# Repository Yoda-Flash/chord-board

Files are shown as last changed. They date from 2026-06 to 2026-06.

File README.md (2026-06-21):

# Chord Board
The Chord Board is a MIDI controller, specifically designed for one to experiment with chords! 
Each note you play can be customized and looped.

I came up with this idea because I've always loved playing with different chords. 
I thought it would be cool to be able to experiment with them without having an actual instrument with me, 
or needing to learn the chords and fingerings to hear different combinations.

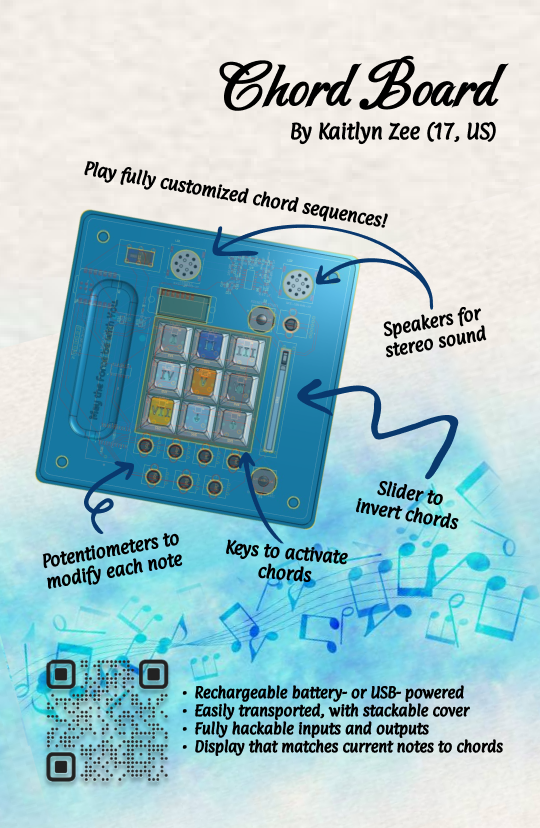
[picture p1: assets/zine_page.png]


## Images
### CAD
Top view:

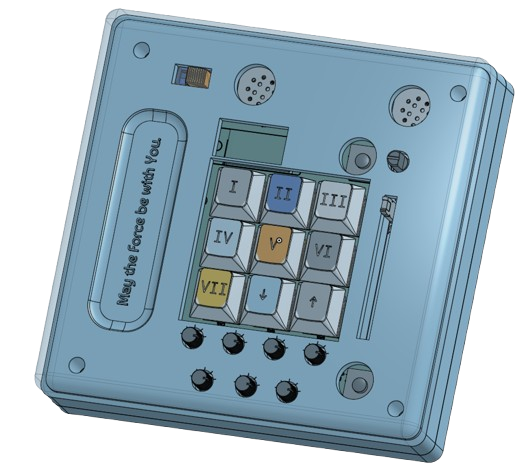
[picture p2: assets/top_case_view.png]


Bottom view:

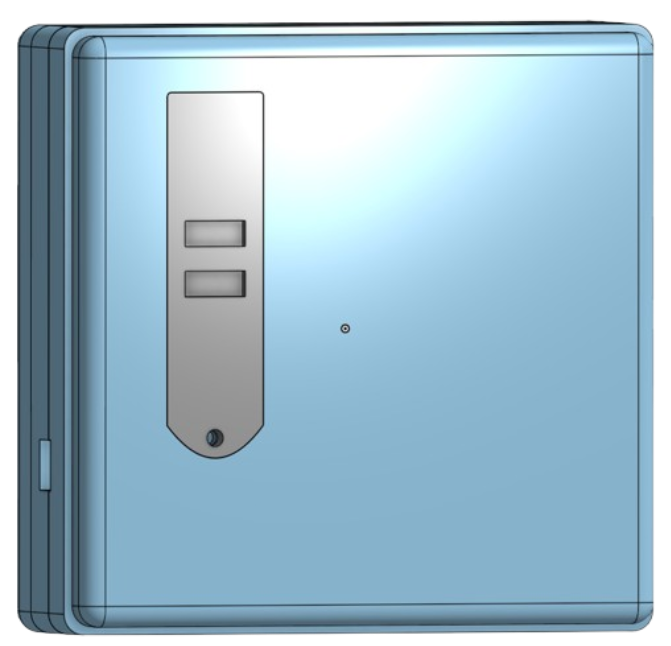
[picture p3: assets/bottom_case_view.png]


CAD of PCB with parts:

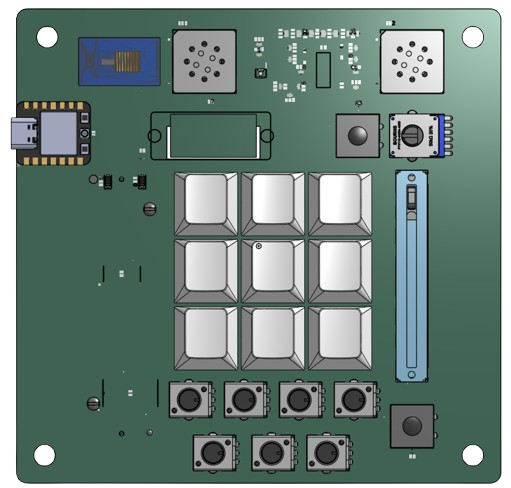
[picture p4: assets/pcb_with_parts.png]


### PCB
PCB:

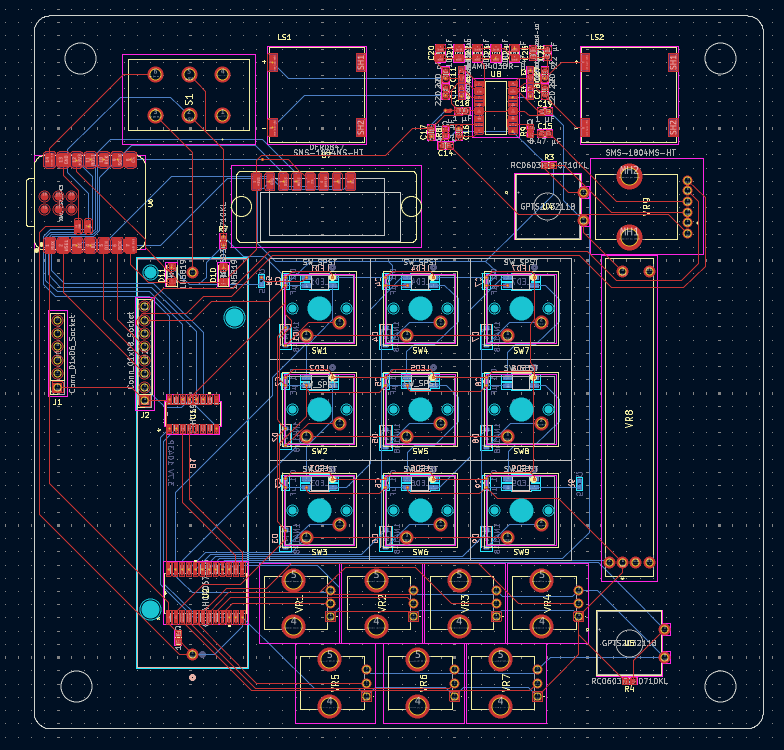
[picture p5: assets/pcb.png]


3D PCB Front:

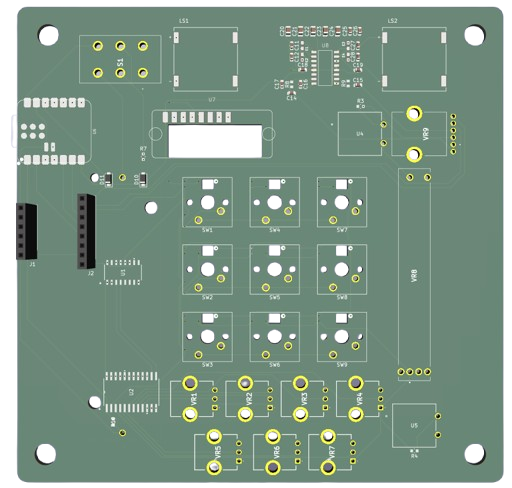
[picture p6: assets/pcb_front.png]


3D PCB Back:

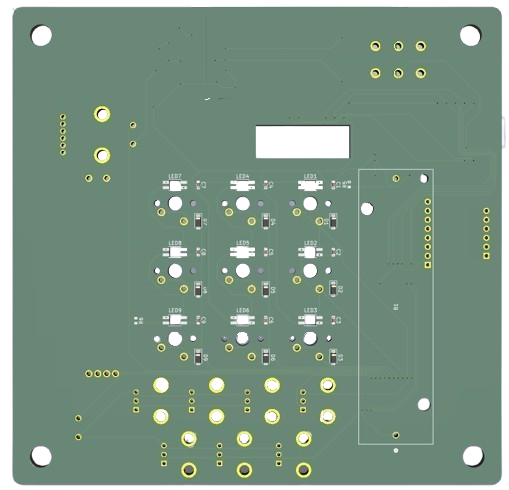
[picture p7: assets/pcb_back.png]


## Features
### Keypad
- 9 keys in a matrix
- 7 keys to activate chords
  - E.g. Pressing "I" will play the root chord, and "V" will play the fifth
- 2 keys to raise or lower the current key (default is C4)

### Rotary Potentiometers
- 7 knobs to modify chords
  - One knob for each note in the chord (1, 3, 5, 7, 9, 11, 13)
  - Each knob has 5 markings: ♭♭, ♭, no modification, #, ## (from left to right)
  - Modifications get applied to the next chord activated
  - If you don't want to include the note in the chord, just rotate the knob to any other position
  - E.g. If the 1st knob is not modified, the 2nd knob is at ♭, and the 3rd knob is not modified, a minor triad will play
- 1 logarithmic knob to adjust volume

### Slide potentiometer
- Inverts the chord depending on how much you slide
  - E.g. If a minor triad is playing and you slide 1/3 of the way, the base note will become the 5th

### Latching buttons
- 1 to cycle through different octaves, between octaves 2 to 6
- 1 to record a loop
  - When pressed, the chord sequence and timing will be recorded
  - When released, the chord sequence will be played back until you re-record or press another key

### TFT Display
- Displays the current key, including the octave, and the notes of the chord being played
  - If the notes being played are matched with a chord, that chord's name will be displayed as well

### Speakers
- Stereo sound
- Left and right speakers connected to a Class D Amplifier

### Power system
- 18650 3.7 V battery 
  - When a USB is plugged into the microcontroller, it will automatically charge
- Switch to power the board on/off
- A cover secures the battery, to be screwed open
  - Comes with a groove for fingers to easily remove the cover

### Stackable Case Cover
- The case comes with a cover, so the device can be transported without fear of accidentally pressing keys or rotating knobs
- The cover can be stacked on the bottom cover, so it doesn't have to lie around when the device is in use

## Bill of Materials
[CSV](bom.csv)

[Excel XLSX](bom.xlsx)

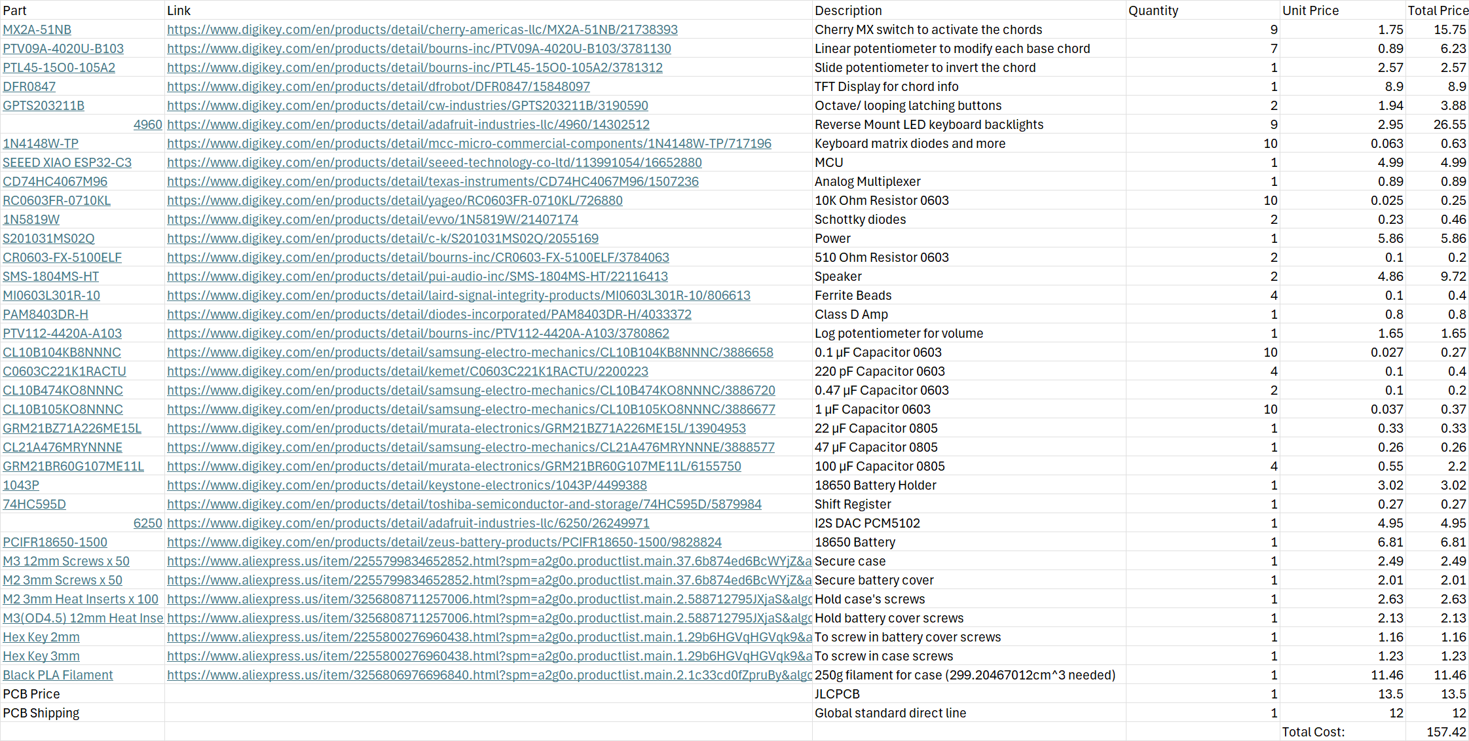
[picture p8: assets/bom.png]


## How to Set Up

### Build Instructions
Gather the assembled PCB and the 3D printed pieces in the [cad folder](./cad), as well as 4 sets of M3 12mm screws and heat inserts and 1 set of M2 3mm screws and heat inserts. 

Use a soldering iron to set the heat inserts in their respective holes (M2 3mm into the bottom case's back holes for the battery cover and M3 12mm for the bottom case's top holes for PCB mounting). Then, place the PCB in between the top and bottom case, and a battery and its cover into the slot on the back. Use a 2mm hex key to screw in the M2 screws and a 3mm hex key for the M3 one.

### Firmware Instructions
The firmware uses Circuit Python, 
so get started with it following https://learn.adafruit.com/welcome-to-circuitpython/installing-circuitpython

Within the Circuit Python drive, 
use pip to install the requirements in `requirements.txt` and transfer the files from `./firmware` to use!

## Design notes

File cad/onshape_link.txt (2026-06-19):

https://cad.onshape.com/documents/d37356e62e43a0eb5440c952/w/cc24309538963043d8ab08ae/e/3163c94926c0e795061b05d7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

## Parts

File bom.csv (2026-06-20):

Part | Link | Description | Quantity | Unit Price | Total Price
MX2A-51NB | https://www.digikey.com/en/products/detail/cherry-americas-llc/MX2A-51NB/21738393 | Cherry MX switch to activate the chords | 9 | 1.75 | 15.75
PTV09A-4020U-B103 | https://www.digikey.com/en/products/detail/bourns-inc/PTV09A-4020U-B103/3781130 | Linear potentiometer to modify each base chord | 7 | 0.89 | 6.23
PTL45-15O0-105A2 | https://www.digikey.com/en/products/detail/bourns-inc/PTL45-15O0-105A2/3781312 | Slide potentiometer to invert the chord | 1 | 2.57 | 2.57
DFR0847 | https://www.digikey.com/en/products/detail/dfrobot/DFR0847/15848097 | TFT Display for chord info | 1 | 8.9 | 8.9
GPTS203211B | https://www.digikey.com/en/products/detail/cw-industries/GPTS203211B/3190590 | Octave/ looping latching buttons | 2 | 1.94 | 3.88
4960 | https://www.digikey.com/en/products/detail/adafruit-industries-llc/4960/14302512 | Reverse Mount LED keyboard backlights | 9 | 2.95 | 26.55
1N4148W-TP | https://www.digikey.com/en/products/detail/mcc-micro-commercial-components/1N4148W-TP/717196 | Keyboard matrix diodes and more | 10 | 0.063 | 0.63
SEEED XIAO ESP32-C3 | https://www.digikey.com/en/products/detail/seeed-technology-co-ltd/113991054/16652880 | MCU | 1 | 4.99 | 4.99
CD74HC4067M96 | https://www.digikey.com/en/products/detail/texas-instruments/CD74HC4067M96/1507236 | Analog Multiplexer | 1 | 0.89 | 0.89
RC0603FR-0710KL | https://www.digikey.com/en/products/detail/yageo/RC0603FR-0710KL/726880 | 10K Ohm Resistor 0603 | 10 | 0.025 | 0.25
1N5819W | https://www.digikey.com/en/products/detail/evvo/1N5819W/21407174 | Schottky diodes | 2 | 0.23 | 0.46
S201031MS02Q | https://www.digikey.com/en/products/detail/c-k/S201031MS02Q/2055169 | Power | 1 | 5.86 | 5.86
CR0603-FX-5100ELF | https://www.digikey.com/en/products/detail/bourns-inc/CR0603-FX-5100ELF/3784063 | 510 Ohm Resistor 0603 | 2 | 0.1 | 0.2
SMS-1804MS-HT | https://www.digikey.com/en/products/detail/pui-audio-inc/SMS-1804MS-HT/22116413 | Speaker | 2 | 4.86 | 9.72
MI0603L301R-10 | https://www.digikey.com/en/products/detail/laird-signal-integrity-products/MI0603L301R-10/806613 | Ferrite Beads | 4 | 0.1 | 0.4
PAM8403DR-H | https://www.digikey.com/en/products/detail/diodes-incorporated/PAM8403DR-H/4033372 | Class D Amp | 1 | 0.8 | 0.8
PTV112-4420A-A103 | https://www.digikey.com/en/products/detail/bourns-inc/PTV112-4420A-A103/3780862 | Log potentiometer for volume | 1 | 1.65 | 1.65
CL10B104KB8NNNC | https://www.digikey.com/en/products/detail/samsung-electro-mechanics/CL10B104KB8NNNC/3886658 | 0.1 µF Capacitor 0603 | 10 | 0.027 | 0.27
C0603C221K1RACTU | https://www.digikey.com/en/products/detail/kemet/C0603C221K1RACTU/2200223 | 220 pF Capacitor 0603 | 4 | 0.1 | 0.4
CL10B474KO8NNNC | https://www.digikey.com/en/products/detail/samsung-electro-mechanics/CL10B474KO8NNNC/3886720 | 0.47 µF Capacitor 0603 | 2 | 0.1 | 0.2
CL10B105KO8NNNC | https://www.digikey.com/en/products/detail/samsung-electro-mechanics/CL10B105KO8NNNC/3886677 | 1 µF Capacitor 0603 | 10 | 0.037 | 0.37
GRM21BZ71A226ME15L | https://www.digikey.com/en/products/detail/murata-electronics/GRM21BZ71A226ME15L/13904953 | 22 µF Capacitor 0805 | 1 | 0.33 | 0.33
CL21A476MRYNNNE | https://www.digikey.com/en/products/detail/samsung-electro-mechanics/CL21A476MRYNNNE/3888577 | 47 µF Capacitor 0805 | 1 | 0.26 | 0.26
GRM21BR60G107ME11L | https://www.digikey.com/en/products/detail/murata-electronics/GRM21BR60G107ME11L/6155750 | 100 µF Capacitor 0805 | 4 | 0.55 | 2.2
1043P | https://www.digikey.com/en/products/detail/keystone-electronics/1043P/4499388 | 18650 Battery Holder | 1 | 3.02 | 3.02
74HC595D | https://www.digikey.com/en/products/detail/toshiba-semiconductor-and-storage/74HC595D/5879984 | Shift Register | 1 | 0.27 | 0.27
6250 | https://www.digikey.com/en/products/detail/adafruit-industries-llc/6250/26249971 | I2S DAC PCM5102 | 1 | 4.95 | 4.95
PCIFR18650-1500 | https://www.digikey.com/en/products/detail/zeus-battery-products/PCIFR18650-1500/9828824 | 18650 Battery | 1 | 6.81 | 6.81
M3 12mm Screws x 50 | https://www.aliexpress.us/item/2255799834652852.html?curPageLogUid=YDdz2iuLNXm6 | Secure case | 1 | 2.49 | 2.49
M2 3mm Screws x 50 | https://www.aliexpress.us/item/2255799834652852.html?curPageLogUid=YDdz2iuLNXm6 | Secure battery cover | 1 | 2.01 | 2.01
M2 3mm Heat Inserts x 100 | https://www.aliexpress.us/item/3256808711257006.html?curPageLogUid=6LOCmPzaGrDu | Hold case's screws | 1 | 2.63 | 2.63
M3(OD4.5) 12mm Heat Inserts x 100 | https://www.aliexpress.us/item/3256808711257006.html?curPageLogUid=6LOCmPzaGrDu | Hold battery cover screws | 1 | 2.13 | 2.13
Hex Key 2mm | https://www.aliexpress.us/item/2255800276960438.html?curPageLogUid=hPayhJG0pxXX | To screw in battery cover screws | 1 | 1.16 | 1.16
Hex Key 3mm | https://www.aliexpress.us/item/2255800276960438.html?curPageLogUid=hPayhJG0pxXX | To screw in case screws | 1 | 1.23 | 1.23
Black PLA Filament | https://www.aliexpress.us/item/3256806976696840.html?curPageLogUid=lXV8t9sE9sV8 | 250g filament for case (299.20467012cm^3 needed) | 1 | 11.46 | 11.46
PCB Price |  | JLCPCB | 1 | 13.5 | 13.5
PCB Shipping |  | Global standard direct line | 1 | 12 | 12
 |  |  |  | Total Cost: | 157.42

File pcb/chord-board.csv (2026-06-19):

Reference | Value | Datasheet | Footprint | Qty | DNP
B1 | 3.7V 1043P | 1043P | chord-board:BATT_1043P_KEY | 1
C1,C2,C3,C4,C5,C6,C7,C8,C9,C16 | 0.1 µF |  | Capacitor_SMD:C_0603_1608Metric | 10
C11,C12,C27,C28 | 220 pF |  | Capacitor_SMD:C_0603_1608Metric | 4
C14,C15 | 0.47 µF |  | Capacitor_SMD:C_0603_1608Metric | 2
C17,C18,C19,C25 | 1 µF |  | Capacitor_SMD:C_0603_1608Metric | 4
C20,C21,C22,C23 | 100 µF |  | Capacitor_SMD:C_0805_2012Metric | 4
C24 | 47 µF |  | Capacitor_SMD:C_0805_2012Metric | 1
C26 | 22 µF |  | Capacitor_SMD:C_0603_1608Metric | 1
D1,D2,D3,D4,D5,D6,D7,D8,D9 | 1N4148 | https://assets.nexperia.com/documents/data-sheet/1N4148_1N4448.pdf | Diode_SMD:D_SOD-123 | 9
D10,D11 | 1N5819 | http://www.vishay.com/docs/88525/1n5817.pdf | Diode_SMD:D_SOD-123F | 2
E1,E2,E3,E4 | MI0603L301R-10 |  | chord-board:FB_MI0603L301R-10 | 4
J1 | Conn_01x06_Socket |  | Connector_PinSocket_2.54mm:PinSocket_1x06_P2.54mm_Vertical | 1
J2 | Conn_01x08_Socket |  | Connector_PinSocket_2.54mm:PinSocket_1x08_P2.54mm_Vertical | 1
LED1,LED2,LED3,LED4,LED5,LED6,LED7,LED8,LED9 | SK6812-E 4960 | 4960 | chord-board:SK6812-E 4960_ADA | 9
LS1,LS2 | SMS-1804MS-HT |  | chord-board:SPKR_SMS-1804MS-HT | 2
R3,R4,R7 | RC0603FR-0710KL | RC0603FR-0710KL | chord-board:RC0603N_YAG | 3
R5,R6 | 510 Ω |  | chord-board:BO_CR0603 510 Ohms | 2
R8,R9,R10 | 10 kΩ |  | chord-board:BO_CR0603 510 Ohms,chord-board:RC0603N_YAG | 3
S1 | S201031MS02Q | https://www.digikey.ph/en/products/detail/c-k/S201031MS02Q/2055169?msockid=2ab7f999c9c96f4c2a13ec8dc8dd6eef | chord-board:S201031MS02Q | 1
SW1,SW2,SW3,SW4,SW5,SW6,SW7,SW8,SW9 | SW_SPST |  | Button_Switch_Keyboard:SW_Cherry_MX_1.00u_PCB | 9
U1 | 74HC595D | https://toshiba.semicon-storage.com/info/docget.jsp?did=36768&prodName=74HC595D | chord-board:SOIC16_TOS | 1
U2 | CD74HC4067M96 | https://www.ti.com/lit/gpn/cd74hc4067 | chord-board:CD74HC4067M96 DW24 | 1
U4,U5 | GPTS203211B | GPTS203211B | chord-board:SWITCH_03211B | 2
U6 | XIAO-ESP32-C3 |  | chord-board:XIAO-ESP32-C3-SMD | 1
U7 | DFR0847 |  | chord-board:DFR0874 SMD | 1
U8 | PAM8403DR-H |  | chord-board:PAM8403DR-H | 1
VR1,VR2,VR3,VR4,VR5,VR6,VR7 | PTV09A-4020U-B103 | https://www.bourns.com/docs/product-datasheets/PTV09.pdf | chord-board:PTV09A4020UB103 | 7
VR8 | PTL45-15O0-105A2 | https://www.bourns.com/docs/Product-Datasheets/PTL.pdf | chord-board:PTL4515O0105A2 | 1
VR9 | PTV112-4420A-A103 | https://componentsearchengine.com/Datasheets/1/PTV112-4420A-A103.pdf | chord-board:PTV1124420AA103 | 1

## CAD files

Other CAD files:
production/Chord Board Assembly.step
cad/PCB & Parts.step
cad/Bottom Case.step
cad/Key Caps.step
cad/Top Case.step
cad/Case Cover.step

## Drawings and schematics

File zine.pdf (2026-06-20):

# Chord Board

## By Kaitlyn Zee (17, US)

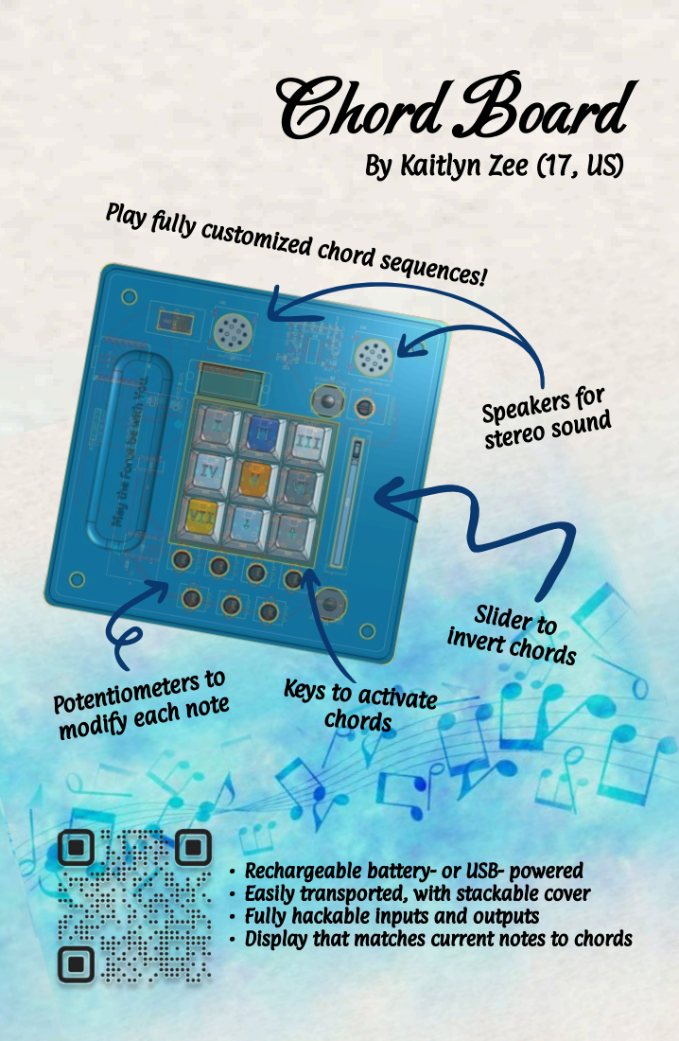
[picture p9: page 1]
Speakers for; stereo sound; Potentiometers to; Slider to invert chords; chords

Play fully customized chord sequences!

Keys to activate

modify each note

Rechargeable battery- or USB- powered
Easily transported, with stackable cover
Fully hackable inputs and outputs
Display that matches current notes to chords

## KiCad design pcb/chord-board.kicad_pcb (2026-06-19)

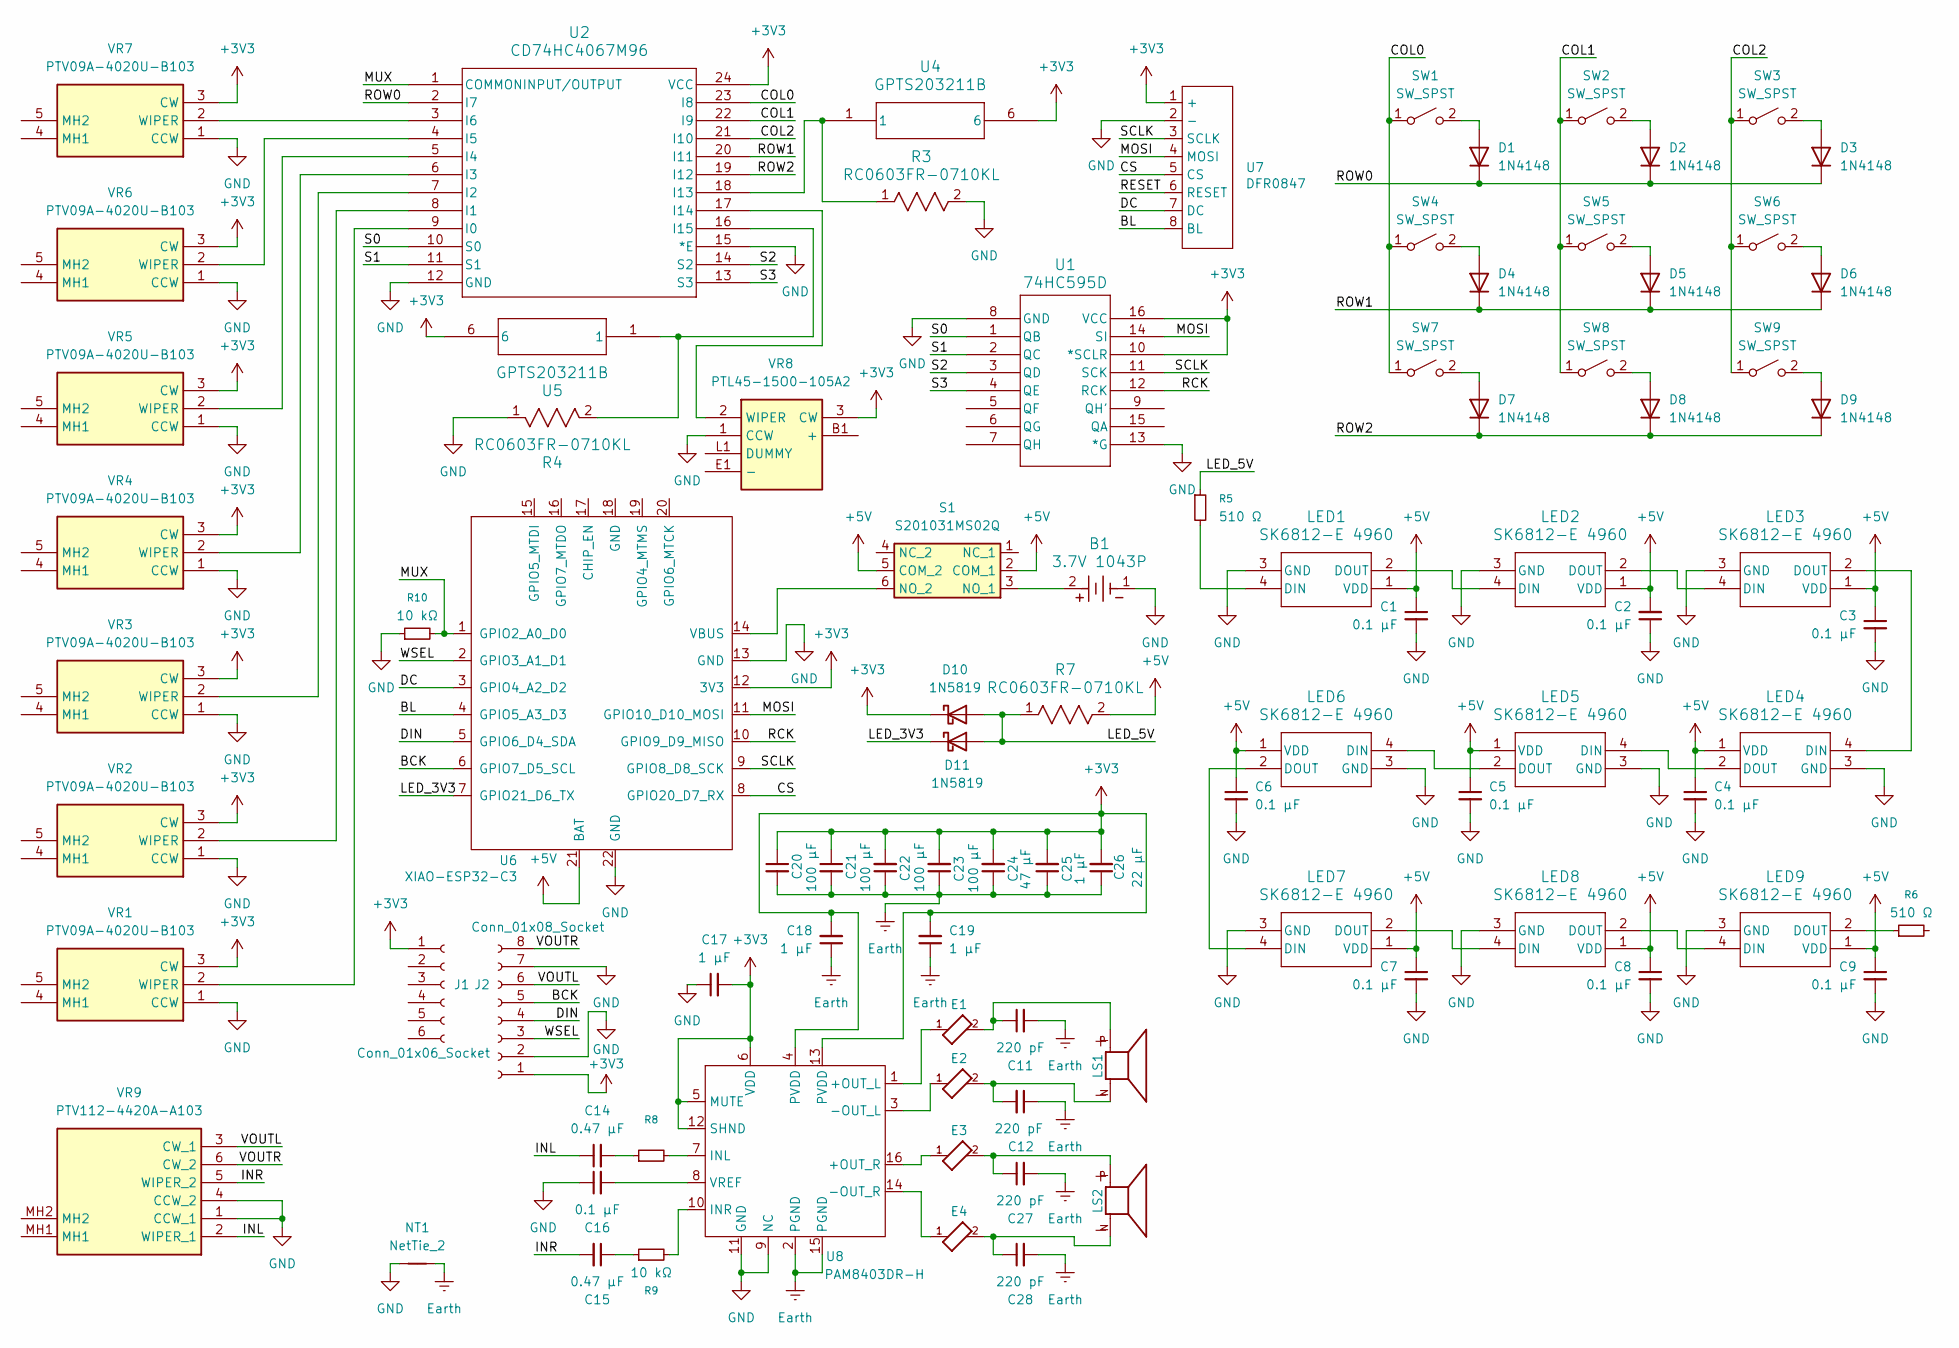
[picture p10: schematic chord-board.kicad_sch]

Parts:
B1: 3.7V 1043P; BATT_1043P_KEY
C1, C2, C3, C4, C5, C6, C7, C8, C9, C16: 0.1 µF; C_0603_1608Metric
C11, C12, C27, C28: 220 pF; C_0603_1608Metric
C14, C15: 0.47 µF; C_0603_1608Metric
C17, C18, C19, C25: 1 µF; C_0603_1608Metric
C20, C21, C22, C23: 100 µF; C_0805_2012Metric
C24: 47 µF; C_0805_2012Metric
C26: 22 µF; C_0603_1608Metric
D1, D2, D3, D4, D5, D6, D7, D8, D9: 1N4148; D_SOD-123
D10, D11: 1N5819; D_SOD-123F
E1, E2, E3, E4: MI0603L301R-10; FB_MI0603L301R-10
J1: Conn_01x06_Socket; PinSocket_1x06_P2.54mm_Vertical
J2: Conn_01x08_Socket; PinSocket_1x08_P2.54mm_Vertical
LED1, LED2, LED3, LED4, LED5, LED6, LED7, LED8, LED9: SK6812-E 4960; SK6812-E 4960_ADA
LS1, LS2: SMS-1804MS-HT; SPKR_SMS-1804MS-HT; PARTREV A
NT1: NetTie_2; NetTie-2_SMD_Pad0.5mm
R3, R4, R7: RC0603FR-0710KL; RC0603N_YAG
R5, R6: 510 Ω; BO_CR0603 510 Ohms
R8, R9: 10 kΩ; BO_CR0603 510 Ohms
R10: 10 kΩ; RC0603N_YAG
S1: S201031MS02Q; Manufacturer_Part_Number S201031MS02Q; Mouser Part Number 611-S201031MS02Q
SW1, SW2, SW3, SW4, SW5, SW6, SW7, SW8, SW9: SW_SPST; SW_Cherry_MX_1.00u_PCB
U1: 74HC595D; SOIC16_TOS
U2: CD74HC4067M96; CD74HC4067M96 DW24
U4, U5: GPTS203211B; SWITCH_03211B
U6: XIAO-ESP32-C3; XIAO-ESP32-C3-SMD
U7: DFR0847; DFR0874 SMD
U8: PAM8403DR-H
VR1, VR2, VR3, VR4, VR5, VR6, VR7: PTV09A-4020U-B103; PTV09A4020UB103; Manufacturer_Part_Number PTV09A-4020U-B103; Mouser Part Number 652-PTV09A-4020UB103
VR8: PTL45-15O0-105A2; PTL4515O0105A2; Manufacturer_Part_Number PTL45-15O0-105A2; Mouser Part Number 652-PTL45-15O0-105A2
VR9: PTV112-4420A-A103; PTV1124420AA103; Manufacturer_Part_Number PTV112-4420A-A103; Mouser Part Number 652-PTV112-4420AA103

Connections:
+3V3: C17.2, C18.2, C19.2, C20.1, C21.1, C22.2, C23.2, C24.2, C25.2, C26.2, D10.1 (K), J1.1 (Pin_1_1), J2.1, U1.10 (*SCLR), U1.16 (VCC), U2.24 (VCC), U4.6, U5.6, U6.12 (3V3), U7.1 (+), U8.4 (PVDD), U8.5 (MUTE), U8.6 (VDD), U8.12 (SHND), U8.13 (PVDD), VR1.3 (CW), VR2.3 (CW), VR3.3 (CW), VR4.3 (CW), VR5.3 (CW), VR6.3 (CW), VR7.3 (CW), VR8.3 (CW)
+5V: C1.1, C2.2, C3.1, C4.1, C5.1, C6.1, C7.1, C8.1, C9.1, LED1.1 (VDD), LED2.1 (VDD), LED3.1 (VDD), LED4.1 (VDD), LED5.1 (VDD), LED6.1 (VDD), LED7.1 (VDD), LED8.1 (VDD), LED9.1 (VDD), R7.2, S1.2 (COM_1), S1.5 (COM_2), U6.21 (BAT)
/BCK: J2.5, U6.6 (GPIO7_D5_SCL)
/BL: U6.4 (GPIO5_A3_D3), U7.8 (BL)
/COL0: SW1.1 (A), SW4.1 (A), SW7.1 (A), U2.23 (I8)
/COL1: SW2.1 (A), SW5.1 (A), SW8.1 (A), U2.22 (I9)
/COL2: SW3.1 (A), SW6.1 (A), SW9.1 (A), U2.21 (I10)
/CS: U6.8 (GPIO20_D7_RX), U7.5 (CS)
/DC: U6.3 (GPIO4_A2_D2), U7.7 (DC)
/DIN: J2.4, U6.5 (GPIO6_D4_SDA)
/INL: C14.1, VR9.2 (WIPER_1)
/INR: C15.2, VR9.5 (WIPER_2)
/LED_3V3: D11.1 (K), U6.7 (GPIO21_D6_TX)
/LED_5V: D10.2 (A), D11.2 (A), R5.1, R7.1
/MOSI: U1.14 (SI), U6.11 (GPIO10_D10_MOSI), U7.4 (MOSI)
/MUX: R10.2, U2.1 (COMMONINPUT/OUTPUT), U6.1 (GPIO2_A0_D0)
/RCK: U1.12 (RCK), U6.10 (GPIO9_D9_MISO)
/RESET: U7.6 (RESET)
/ROW0: D1.1 (K), D2.1 (K), D3.1 (K), U2.2 (I7)
/ROW1: D4.1 (K), D5.1 (K), D6.1 (K), U2.20 (I11)
/ROW2: D7.1 (K), D8.1 (K), D9.1 (K), U2.19 (I12)
/S0: U1.1 (QB), U2.10 (S0)
/S1: U1.2 (QC), U2.11 (S1)
/S2: U1.3 (QD), U2.14 (S2)
/S3: U1.4 (QE), U2.13 (S3)
/SCLK: U1.11 (SCK), U6.9 (GPIO8_D8_SCK), U7.3 (SCLK)
/VOUTL: J2.6, VR9.3 (CW_1)
/VOUTR: J2.8, VR9.6 (CW_2)
/WSEL: J2.3, U6.2 (GPIO3_A1_D1)
Earth: C11.2, C12.1, C18.1, C19.1, C20.2, C21.2, C22.1, C23.1, C24.1, C25.1, C26.1, C27.2, C28.2, NT1.2, U8.2 (PGND), U8.15 (PGND)
GND: B1.1, C1.2, C2.1, C3.2, C4.2, C5.2, C6.2, C7.2, C8.2, C9.2, C16.1, C17.1, J2.2, J2.7, LED1.3 (GND), LED2.3 (GND), LED3.3 (GND), LED4.3 (GND), LED5.3 (GND), LED6.3 (GND), LED7.3 (GND), LED8.3 (GND), LED9.3 (GND), NT1.1, R3.2, R4.1, R10.1, U1.8 (GND), U1.13 (*G), U2.12 (GND), U2.15 (*E), U6.13 (GND), U6.22 (GND), U7.2 (-), U8.9 (NC), U8.11 (GND), VR1.1 (CCW), VR2.1 (CCW), VR3.1 (CCW), VR4.1 (CCW), VR5.1 (CCW), VR6.1 (CCW), VR7.1 (CCW), VR8.1 (CCW), VR9.1 (CCW_1), VR9.4 (CCW_2)
unnamed: C11.1, E1.2, LS1.P
unnamed: C12.2, E2.2, LS1.N
unnamed: C14.2, R8.1
unnamed: C15.1, R9.1
unnamed: C27.1, E3.2, LS2.P
unnamed: C28.1, E4.2, LS2.N
unnamed: D1.2 (A), SW1.2 (B)
unnamed: D2.2 (A), SW2.2 (B)
unnamed: D3.2 (A), SW3.2 (B)
unnamed: D4.2 (A), SW4.2 (B)
unnamed: D5.2 (A), SW5.2 (B)
unnamed: D6.2 (A), SW6.2 (B)
unnamed: D7.2 (A), SW7.2 (B)
unnamed: D8.2 (A), SW8.2 (B)
unnamed: D9.2 (A), SW9.2 (B)
unnamed: LED1.4 (DIN), R5.2
unnamed: LED1.2 (DOUT), LED2.4 (DIN)
unnamed: LED2.2 (DOUT), LED3.4 (DIN)
unnamed: LED3.2 (DOUT), LED4.4 (DIN)
unnamed: LED4.2 (DOUT), LED5.4 (DIN)
unnamed: LED5.2 (DOUT), LED6.4 (DIN)
unnamed: LED6.2 (DOUT), LED7.4 (DIN)
unnamed: LED7.2 (DOUT), LED8.4 (DIN)
unnamed: LED8.2 (DOUT), LED9.4 (DIN)
unnamed: LED9.2 (DOUT), R6.1
unnamed: B1.2, S1.3 (NO_1)
unnamed: S1.6 (NO_2), U6.14 (VBUS)
unnamed: U2.9 (I0), VR1.2 (WIPER)
unnamed: U2.8 (I1), VR2.2 (WIPER)
unnamed: U2.7 (I2), VR3.2 (WIPER)
unnamed: U2.6 (I3), VR4.2 (WIPER)
unnamed: U2.5 (I4), VR5.2 (WIPER)
unnamed: U2.4 (I5), VR6.2 (WIPER)
unnamed: U2.3 (I6), VR7.2 (WIPER)
unnamed: R3.1, U2.18 (I13), U4.1
unnamed: U2.17 (I14), VR8.2 (WIPER)
unnamed: R4.2, U2.16 (I15), U5.1
unnamed: E1.1, U8.1 (+OUT_L)
unnamed: E3.1, U8.16 (+OUT_R)
unnamed: E2.1, U8.3 (-OUT_L)
unnamed: E4.1, U8.14 (-OUT_R)
unnamed: R8.2, U8.7 (INL)
unnamed: R9.2, U8.10 (INR)
unnamed: C16.2, U8.8 (VREF)

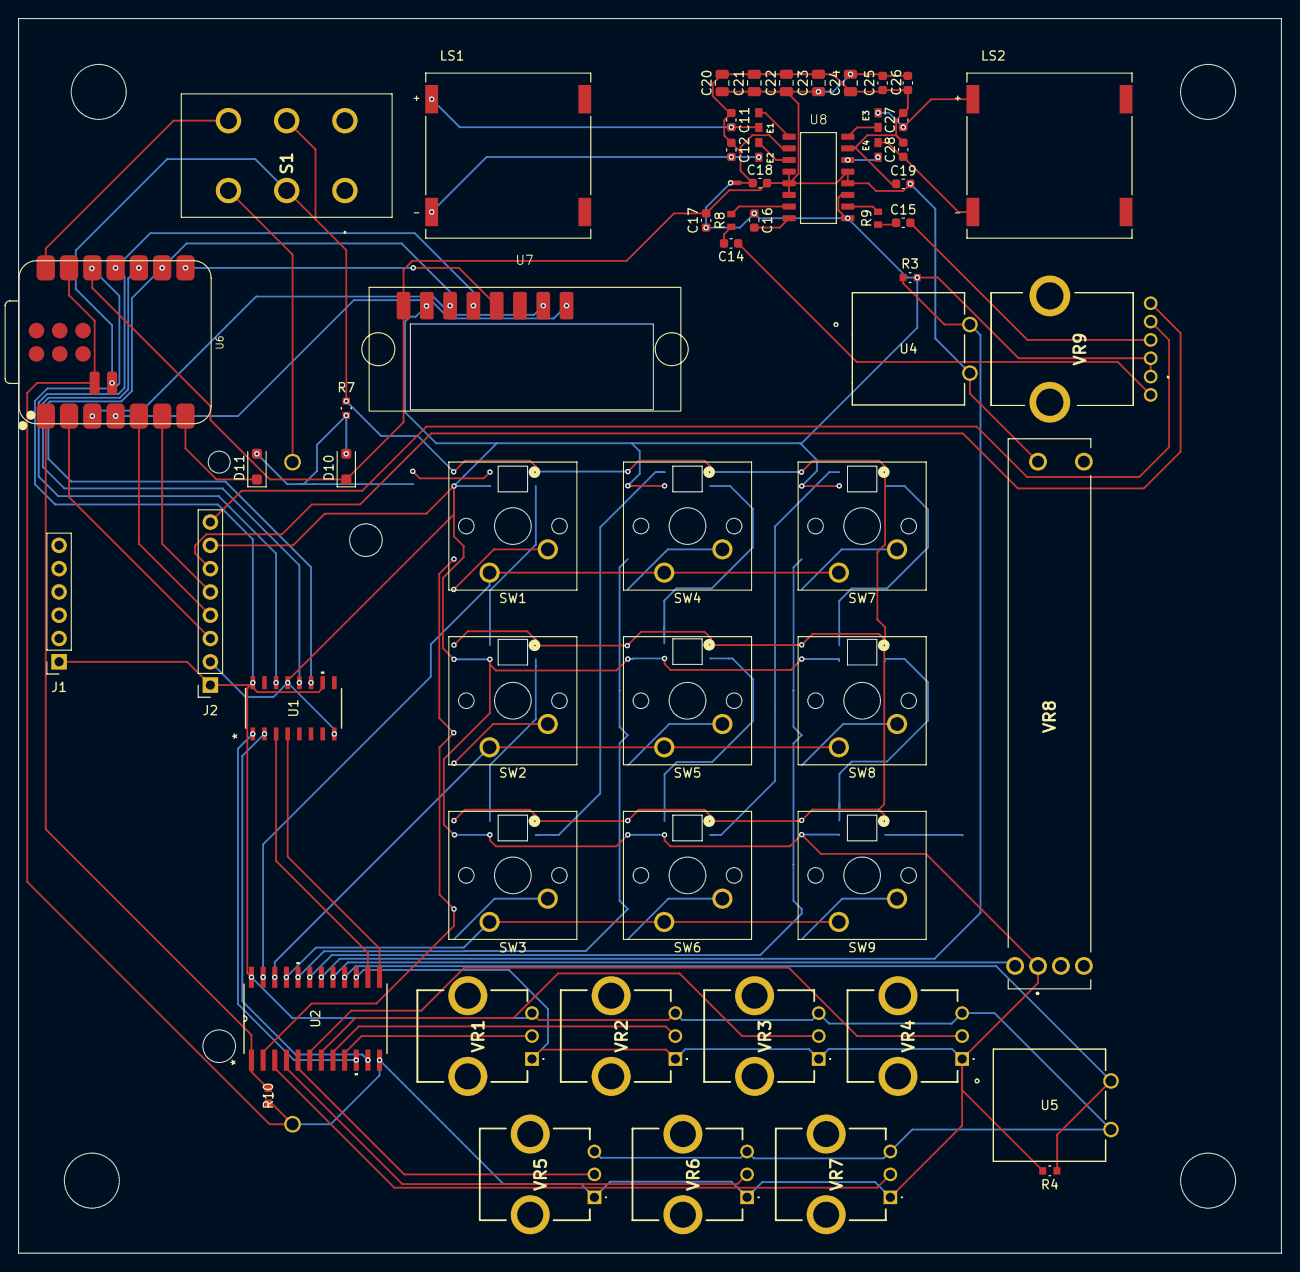
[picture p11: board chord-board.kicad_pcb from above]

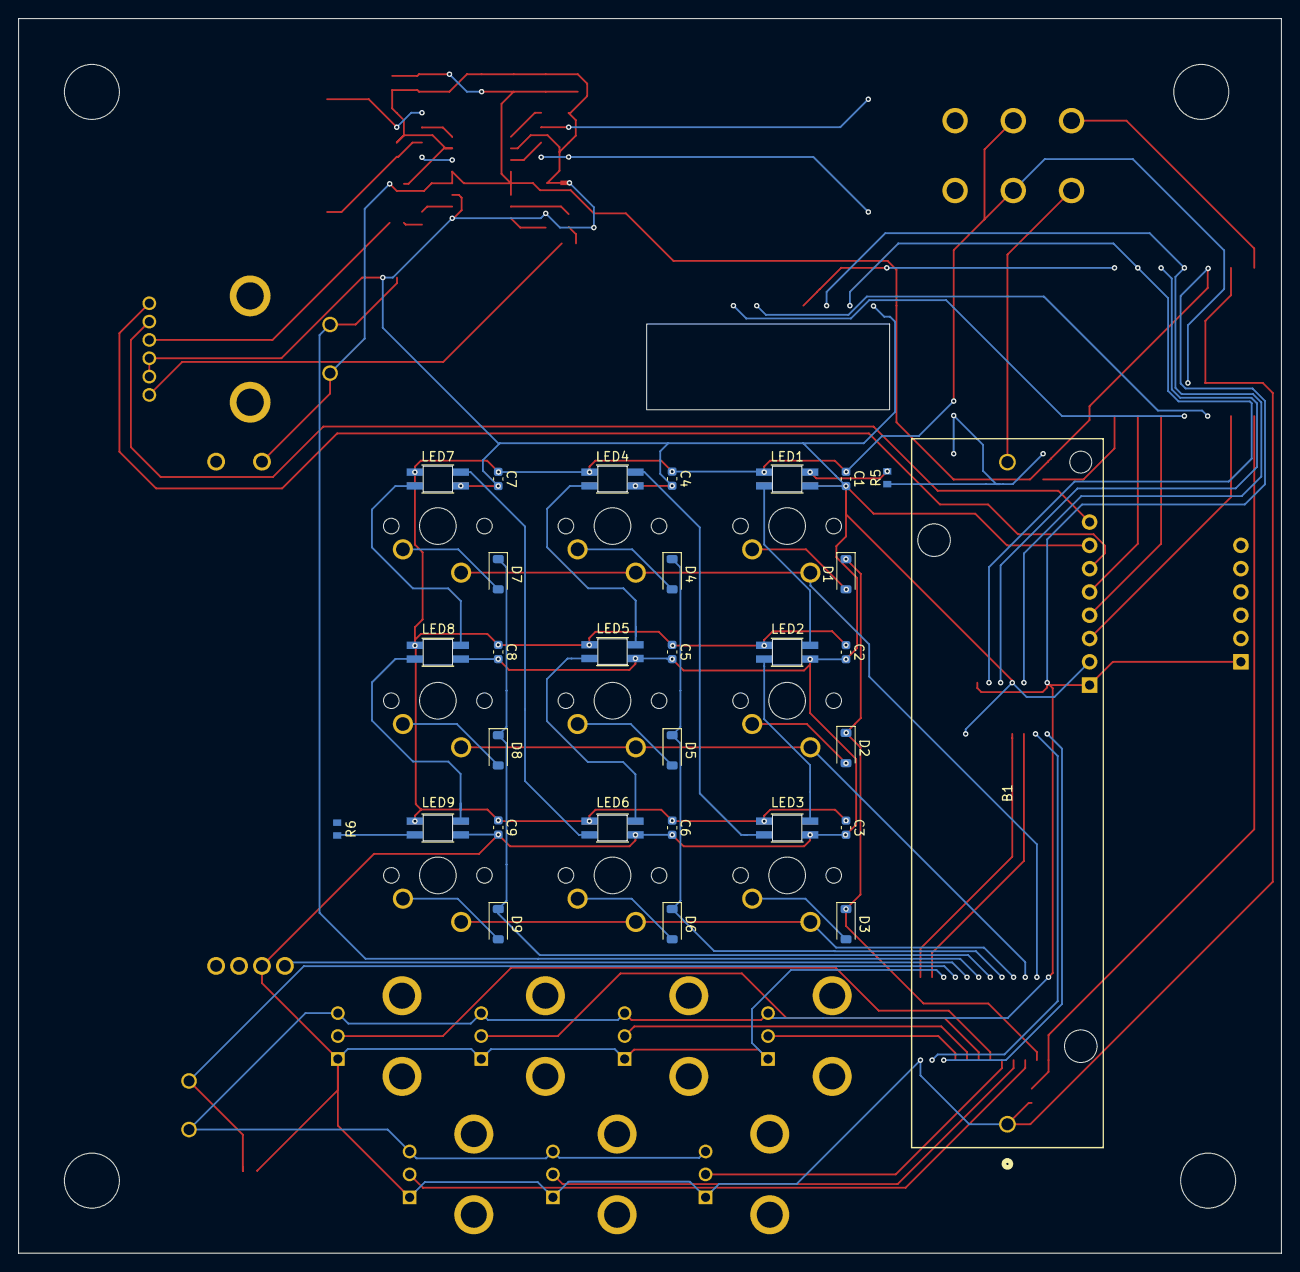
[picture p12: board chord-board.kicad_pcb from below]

Board: 2 copper layers, 137.7 x 134.7 mm, 90 parts (30 on the bottom side), 74 nets.

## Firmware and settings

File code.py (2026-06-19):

import math

import board
import terminalio
from displayio import Group, release_displays
from adafruit_display_text import label
from adafruit_74hc595 import ShiftRegister74HC595
from adafruit_st7735 import ST7735
from analogio import AnalogIn, AnalogOut
from audiobusio import I2SOut
from digitalio import DigitalInOut, Direction
from fourwire import FourWire
from synthio import Synthesizer

from midi_tools import note_or_name

board_voltage = 3.3
voltage_tolerance = 0.5

# Shift register init
sr_latch_pin = DigitalInOut(board.D9)
sr = ShiftRegister74HC595(board.SPI(), sr_latch_pin)

select_pins = [sr.get_pin(pin) for pin in range(1, 5)]
for pin in select_pins:
    pin.direction = Direction.OUTPUT

# Analog multiplexer init

mux_pin = AnalogIn(board.A0)
# mux_pins = ["1", "3", "5", "7", "9", "11", "13", "row0", "col0", "col1", "col2", "row1", "row2", "loop", "invert", "octave"]

# Inputs init
row_pins = [7, 11, 12]
col_pins = [8, 9, 10]
keys = [["I", "II", "III"], ["IV", "V", "VI"], ["VII", "keyup", "keydown"]]
chord_labels = ["I", "II", "III", "IV", "V", "VI", "VII"]
pressed_keys = []

pot_voltage_bounds = [[0.0, 0.5], [0.6, 1.0], [1.2, 1.8], [2.0, 2.6], [2.8, 3.3]] # TODO: Fill with actual voltage max/min boundary at each marking when testing the physical board

invert_pin = 14
octave_pin = 13
loop_pin = 15

# TFT screen init
release_displays()

display_bus = FourWire(board.SPI(), command=board.D2, chip_select=board.D7)
display = ST7735(display_bus, width=160, height=80, rotation=180)

splash = Group()
text_group = Group(scale=2, x=10, y=10) # TODO: Figure out a good offset for the words when testing physical board

# DAC for speaker init
audio = I2SOut(board.D5, board.D1, board.D4)

# Synth for playing music
synth = Synthesizer(sample_rate=44100)
audio.play(synth)

# Processing variables init
current_octave = 4
current_key = note_or_name(f"C{current_octave}")
root_note = current_key
rel_notes = []
notes = []

CHORD_NAMES = {
    "maj": [0, 4, 7],
    "min": [0, 3, 7],
    "aug": [0, 4, 8],
    "dim": [0, 3, 6],
    "sus": [0, 5, 7],
    "sus2": [0, 2, 7],
    "6": [0, 4, 7, 9],
    "(add2), (add9)": [0, 2, 4, 7],
    "maj7": [0, 4, 7, 11],
    "7": [0, 4, 7, 10],
    "7♭5": [0, 4, 6, 10],
    "7sus": [0, 5, 7, 10],
    "m(add2), m(add9)": [0, 2, 3, 7],
    "m6": [0, 3, 7, 9],
    "m7": [0, 3, 7, 10],
    "m(maj7)": [0, 3, 7, 11],
    "m7♭5": [0, 3, 6, 10],
    "dim7": [0, 3, 6, 9],
    "5": [0, 7],
    "maj7♯11": [0, 4, 7, 11, 18],
    "maj9": [0, 4, 7, 11, 14],
    "7♯9": [0, 4, 7, 10, 15],
    "9": [0, 4, 7, 10, 14],
    "11, 9(sus4)": [0, 7, 10, 14, 17],
    "13": [0, 4, 7, 10, 14, 21],
    "m9": [0, 3, 7, 10, 14],
    "m11": [0, 3, 7, 10, 17]
}

chord_sequence = []
timer = 0
time_sequence = []
is_recording_loop = False
loop_pos = 0

def get_analog_voltage(mux_pin):
    return (mux_pin.value / 65536)*board_voltage


def number_to_bits(number):
    number = number & 0xF
    return format(number, '04b')


def bits_to_booleans(bits: str):
    booleans = []
    for bit in bits:
        booleans.append(True if bit == '1' else False)
    return booleans


def set_select_pins(pin, select_pins):
    booleans = bits_to_booleans(number_to_bits(pin))
    i = 0
    while i < 4:
        select_pins[i].value = booleans[i]
        i += 1


def raise_key(key):
    key += 1
    if key > note_or_name(f"C{current_octave+1}"):
        key - 12
    return key


def lower_key(key):
    key -= 1
    if key < note_or_name(f"C{current_octave-1}"):
        key + 12
    return key


def get_rel_note_num_from_index(index):
    return index*2


def get_note_mod_from_index(index):
    return index - 2


def invert_chord(notes, voltage):
    num_inversions = math.floor(board_voltage - voltage)/(board_voltage/len(notes)) # Assuming linear voltage by slider's distance, divide voltage by the proportion of the slider's distance
    if num_inversions == 0:
        return notes
    shifted_notes = [(note - 12) for note in notes[-num_inversions:]]
    del notes[-num_inversions:]
    return shifted_notes + notes


def cycle_octave(octave):
    octave += 1
    if octave > 6:
        octave = 2
    return octave


def update_key(key):
    keystring = note_or_name(key)[:1] # Isolates the key without the octave designation
    return note_or_name(f"{keystring}{current_octave}")


def next_loop_pos(pos, len):
    pos += 1
    if pos >= len:
        pos = 0
    return pos


def get_chord_notes(notes):
    return "  ".join(notes)


def get_chord_name(rel_notes):
    reordered_notes = [note + 12 if note < 0 else note for note in rel_notes]

    for name, notes in CHORD_NAMES.items():
        if notes == reordered_notes:
            return f" - {name}"
    return ""


def get_base_note(notes):
    if notes[0] != 0:
        return f" / {note_or_name(notes[0])}"
    else:
        return ""

while True:
    # Read from Analog Multiplexer first
    pin_readings = []
    pressed_keys = []
    for pin in range(0, 16):
        set_select_pins(pin, select_pins)

        pin_readings.append(get_analog_voltage(mux_pin))

        if pin in row_pins:
            mux_pin.deinit()
            mux_pin = AnalogOut(board.A0)
            mux_pin.value = 0
            for col in col_pins:
                set_select_pins(col, select_pins)

                mux_pin.deinit()
                mux_pin = AnalogIn(board.A0)
                if abs(get_analog_voltage(mux_pin)-board_voltage) <= voltage_tolerance:
                    pressed_keys.append(keys[pin][col])

    pot_readings = pin_readings[:7]
    for reading_index, reading in enumerate(pot_readings):
        for bound_index, bound in enumerate(pot_voltage_bounds):
            if bound[0] <= reading <= bound[1]:
                note = get_rel_note_num_from_index(reading_index)
                mod = get_note_mod_from_index(bound_index)
                rel_notes.append(note + mod)
                break

    invert_chord(rel_notes, pin_readings[invert_pin])

    if abs(pin_readings[octave_pin] - board_voltage) < voltage_tolerance:
        current_octave = cycle_octave(current_octave)
        current_key = update_key(current_key)

    if abs(pin_readings[loop_pin] - board_voltage) < voltage_tolerance:
        if not is_recording_loop: #Reset at the beginning of each record
            chord_sequence.clear()
            time_sequence.clear()
            timer = 0
            loop_pos = 0
            is_recording_loop = True
        timer += 1
    else:
        if is_recording_loop:
            time_sequence.append(timer)
            timer = 0
            is_recording_loop = False
        if timer > time_sequence[loop_pos]:
            synth.release(chord_sequence[loop_pos])
            loop_pos = next_loop_pos(loop_pos, len(time_sequence))
            synth.press(chord_sequence[loop_pos])

        timer += 1

    for key in pressed_keys:
        if key in chord_labels:
            root_note = current_key + chord_labels.index(key)
            synth.release(notes)
            notes.clear()

            notes = [int(note + root_note) for note in rel_notes]
            synth.press(notes)

            text = f"{note_or_name(current_key)}{get_chord_name(rel_notes)}{get_base_note(notes)} \n {get_chord_notes(notes)}"
            text_label = label.Label(terminalio.FONT, text=text)
            text_group.append(text_label)
            splash.append(text_group)

            if is_recording_loop:
                if timer != 0:
                    time_sequence.append(timer)
                    timer = 0
                chord_sequence.append(notes)

        elif key == "keyup":
            current_key = raise_key(current_key)
        elif key == "keydown":
            current_key = lower_key(current_key)

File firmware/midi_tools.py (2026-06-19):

# Copied from https://github.com/CedarGroveStudios/CircuitPython_MIDI_Tools/blob/main/cedargrove_midi_tools.py

# Note names used by note_or_name, note_name, and name_note helpers
NOTE_BASE = ["C", "C#/D♭", "D", "D#/E♭", "E", "F", "F#/G♭", "G", "G#/A♭", "A", "A#/B♭", "B"]


def note_or_name(value):
    """Bidirectionally translates a MIDI sequential note value to a note name
    or a note name to a MIDI sequential note value. Note values are integers in
    the range of 0 to 127 (inclusive). Note names are character strings
    expressed in the format NoteOctave such as 'C4' or 'G#7'. Note names range
    from 'C-1' (note value 0) to 'F#9' (note value 127). If the input value is
    outside the note value or name range, the value of `None` is returned.

    :param union(int, str) value: The note name or note value input. Note value
    is an integer Note name is a string. No default value.
    """
    if isinstance(value, str):
        # Input is a string, so it's a note name
        return name_to_note(value)
    if isinstance(value, int):
        # Input is an integer, so it's a note value
        return note_to_name(value)
    return None  # Invalid input parameter type


def note_to_name(note):
    """Translates a MIDI sequential note value to a note name. Note values are
    integers in the range of 0 to 127 (inclusive). Note names are character
    strings expressed in the format NoteOctave such as 'C4' or 'G#7'. Note
    names range from 'C-1' (note value 0) to 'F#9' (note value 127). If the
    input value is outside that range, the value of `None` is returned.

    :param int note: The note value input in the range of 0 to 127 (inclusive).
    No default value.
    """
    if 0 <= note <= 127:
        return NOTE_BASE[note % 12] + str((note // 12) - 1)
    return None  # Note value outside valid range


def name_to_note(name):
    """Translates a note name to a MIDI sequential note value. Note names are
    character strings expressed in Scienfic Pitch Notation (NoteOctave) format
    such as 'C4' or 'G#7' with middle C defined as 'C4'. Note names range from
    'C-1' (note value 0) to 'G9' (note value 127). Note values are of integer
    type in the range of 0 to 127 (inclusive). If the input value is outside
    that range, the value of `None` is returned.

    :param str name: The note name input in SPN format. No default value.
    """
    name = name.upper()  # Convert lower to uppercase
    if "-" in name:
        octave = int(name[-2:])
        name = name[:-2]
    else:
        octave = int(name[-1:])
        name = name[:-1]

    if name in NOTE_BASE:
        # Note name is valid
        note = NOTE_BASE.index(name)
        midi_note = note + (12 * (octave + 1))  # MIDI note value
        if 0 <= midi_note <= 127:
            return midi_note
    return None  # Name is invalid or outside MIDI value range

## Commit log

2026-06-19 Finished the BOM and the README!
    [Bottom Case.step, Case Cover.step, Chord Board Assembly.step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]
2026-06-20 Tracked CAD files with LFS
2026-06-20 Cleaned up everything; should be ready to submit!
    [bom.csv, bom.xlsx]
2026-06-20 Added firmware instructions to README, PCB price to BOM, and removed boundaries from Zine
    [bom.csv, bom.xlsx]
2026-06-20 Moved assembly CAD to production folder
    [Chord Board Assembly.step]
